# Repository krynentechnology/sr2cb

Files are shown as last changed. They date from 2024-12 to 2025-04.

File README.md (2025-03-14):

# SR2CB
<p>The Synchronous Redundant Ring Channel Bus (<i>S-R-square-C-Bus</i>) is a data bus with a open ring topology where a data <i>channel</i> is constructed from successive frames fixed bit/bits/byte/word/dword/qword/etc. positions. The
SR2CB network protocol supports <i>synchronous</i> operation by means of a distributed clock mechanism. Each ring node has two full duplex (TX/RX) hardware ports.</p>

<p>The physical interface (<i>layer</i>) between SR2CB nodes is based on 1000BASE-T, 100BASE-TX, RS-485 or LVDS. 1000BASE-T and 100BASE-TX PHYs are also common for the ethernet network physical layer but not bound to transmit solely ethernet frames. The SR2CB frames are continuously transmitted by the ring nodes clockwise and counterclockwise. Slave nodes retransmit those SR2CB frames after receipt and insert or extract channel data 'on the fly'. Within a SR2CB master/slave ring the single master node starts the redundant ring initialization and transmits the SR2CB frames. Master nodes do not pass SR2CB frames around except for a broken redundant ring (<i>single point of failure</i>) or when the redundant ring is exclusivly build from master nodes.</p>

<p>SR2CB (master) protocol HW setup for <a href="c10lp/README.md">Intel&reg; Cyclone&reg; 10 LP Evaluation Kit</a> and <a href="ecp5/README.md">Lattice Semiconductor&reg; ECP5&#8482; Development Board</a>.</p>

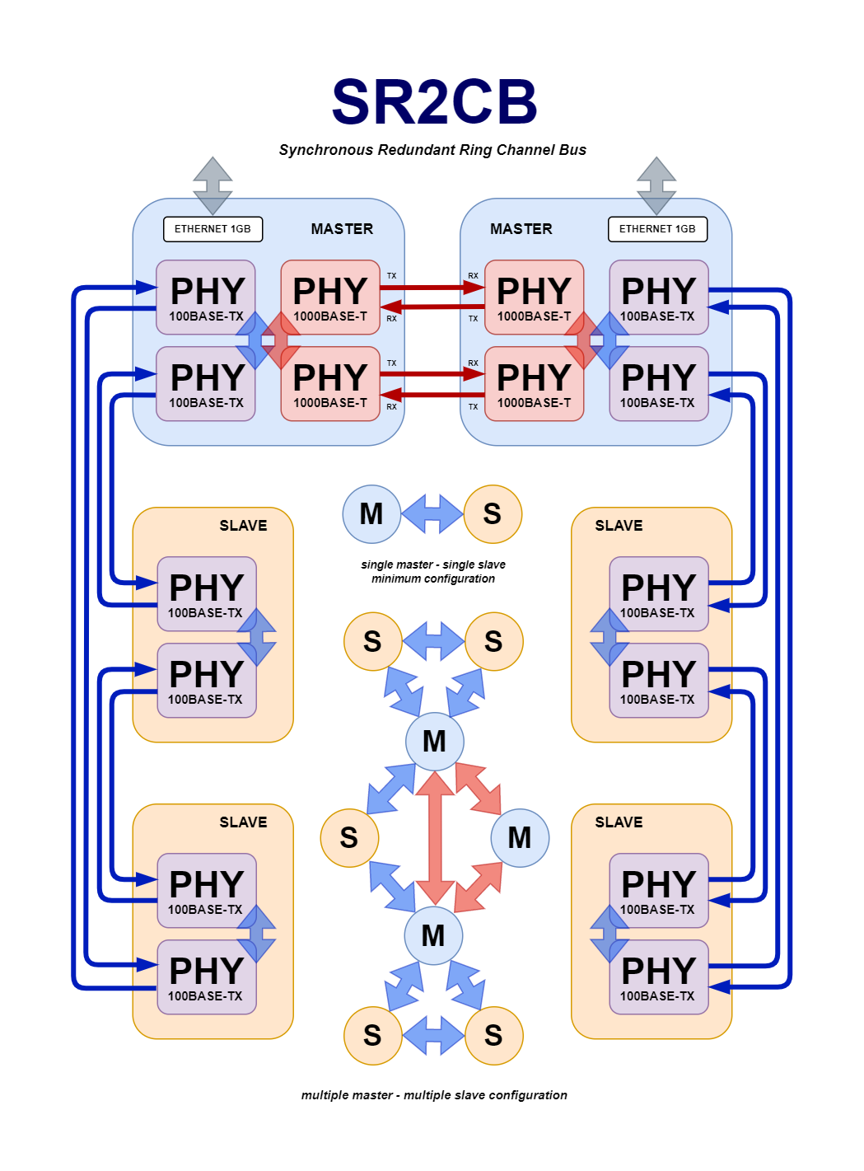
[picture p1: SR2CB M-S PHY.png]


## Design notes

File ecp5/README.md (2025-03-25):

# ECP5
<p>SR2CB protocol HW setup for Lattice Semiconductor&reg; ECP5&#8482; Development Board with cross-wired RJ-45 cable.</p>

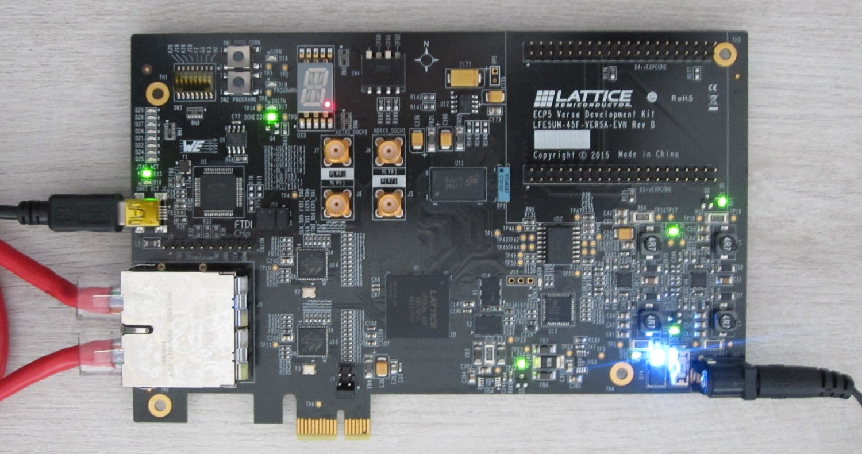
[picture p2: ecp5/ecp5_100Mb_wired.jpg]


<p>The Lattice Semiconductor&reg; ECP5&#8482; Development Board has two 1Gb/s Ethernet PHYs (Marvell 88E1512) and those should be setup for 100Mb/s with a cross-wired RJ-45 cable via a terminal connection. The SR2CB FPGA logic provides an UART/TTL terminal connection via the ECP5&#8482; Development Board FDTI USB port. The ECP5&#8482; Versa Development Board has from factory its FDTI FT2232H EEPROM not correctly configured for UART use. Reconfigure EEPROM by FT_PROG utility from FDTI - "Scan and parse". Set "Hardware Specific" - port B to UART and VCP (Virtual COM Port) and reprogram FT2232H EEPROM.</p>

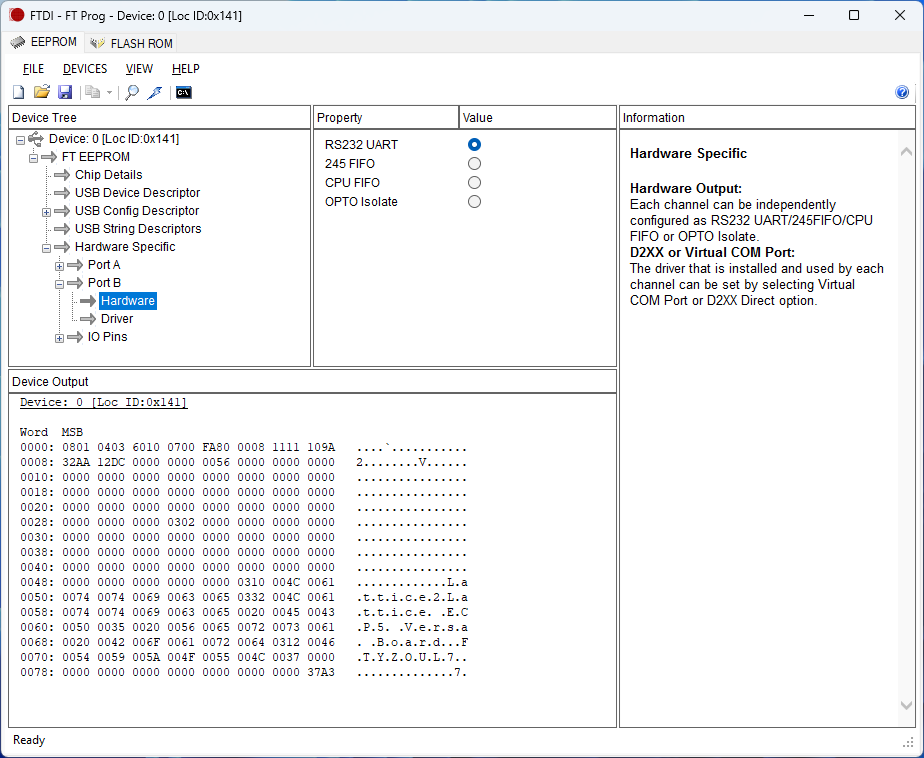
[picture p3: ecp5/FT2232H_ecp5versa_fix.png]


<p>The terminal commands "00A100" and "20A100" (write 0xA100 to PHY1 and PHY2 register 0 - Copper Control) forces the PHYs to 100Mb full duplex. Force link up for a continuous PHYs RXCLK with terminal commands "100400" and "300400" (write 0x0400 to PHY1 and PHY2 register 16 - 0x10/0x30). Read PHYs register 17 - 0x11/0x31 (Copper Specific Status Register 1 - 100Mbps, full duplex, auto-negotiation resolved and (copper) link-up). The terminal command "803" sets the PHYs link up bits in the SR2CB FPGA logic and the SR2CB master starts sending SR2CB frames. The ring 0 and 1 status is shown by "80" and "81" (4 = eR_READY).</p>

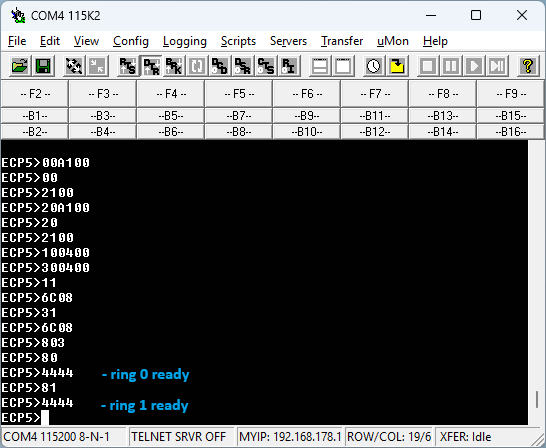
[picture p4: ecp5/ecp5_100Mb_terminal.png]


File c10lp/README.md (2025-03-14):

# C10LP
<p>SR2CB (master) protocol HW setup for Intel&reg; Cyclone&reg; 10 LP Evaluation Kit with 100Mb (fast ethernet) RJ-45 loopback plug - connect pin 1 (TX+) to 3 (RX+) and pin 2 (TX-) to 6 (RX-).</p>

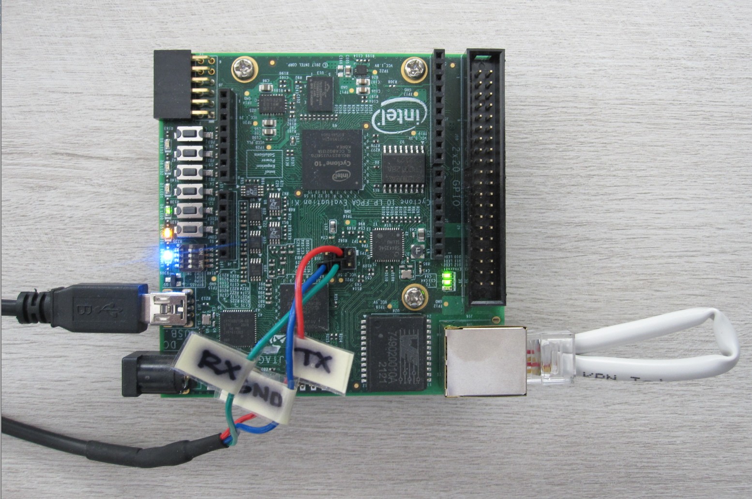
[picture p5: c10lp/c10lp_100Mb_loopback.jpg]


<p>The Intel&reg; Cyclone&reg; 10 LP Evaluation Kit has a 1Gb/s Ethernet PHY (MaxLinear GPY111-PEF7071) and should be setup for 100Mb/s with a two-wired RJ-45 loopback plug via a terminal connection. The SR2CB FPGA logic provides an UART/TTL terminal connection via three pins (RX/TX/GND) of the C10LP J18 haeder. The terminal command "002100" (write 0x2100 to PHY register 0x00 STD_CTRL) forces the PHY to 100Mb full duplex - 100Mb and linkup LEDs should light. Read PHY registers 0x17 (PCY_MIICTRL - RXCLK is active also when link is down, copper data flow, RGMII mode) and 0x18 (PHY_MIISTAT - full duplex, 100Mbit/s) to verify set configuration.</p>

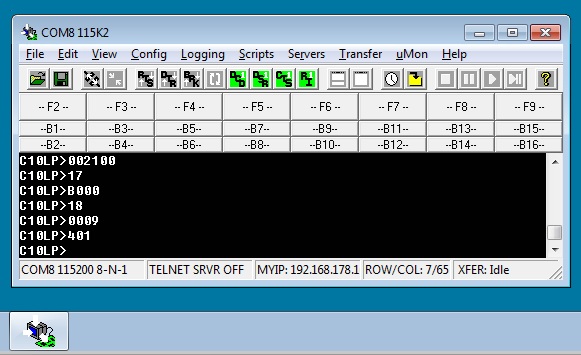
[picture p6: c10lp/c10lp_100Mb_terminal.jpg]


<p>The terminal command "401" sets the PHY link up bit in the SR2CB FPGA logic and the SR2CB master starts sending SR2CB frames.</p>

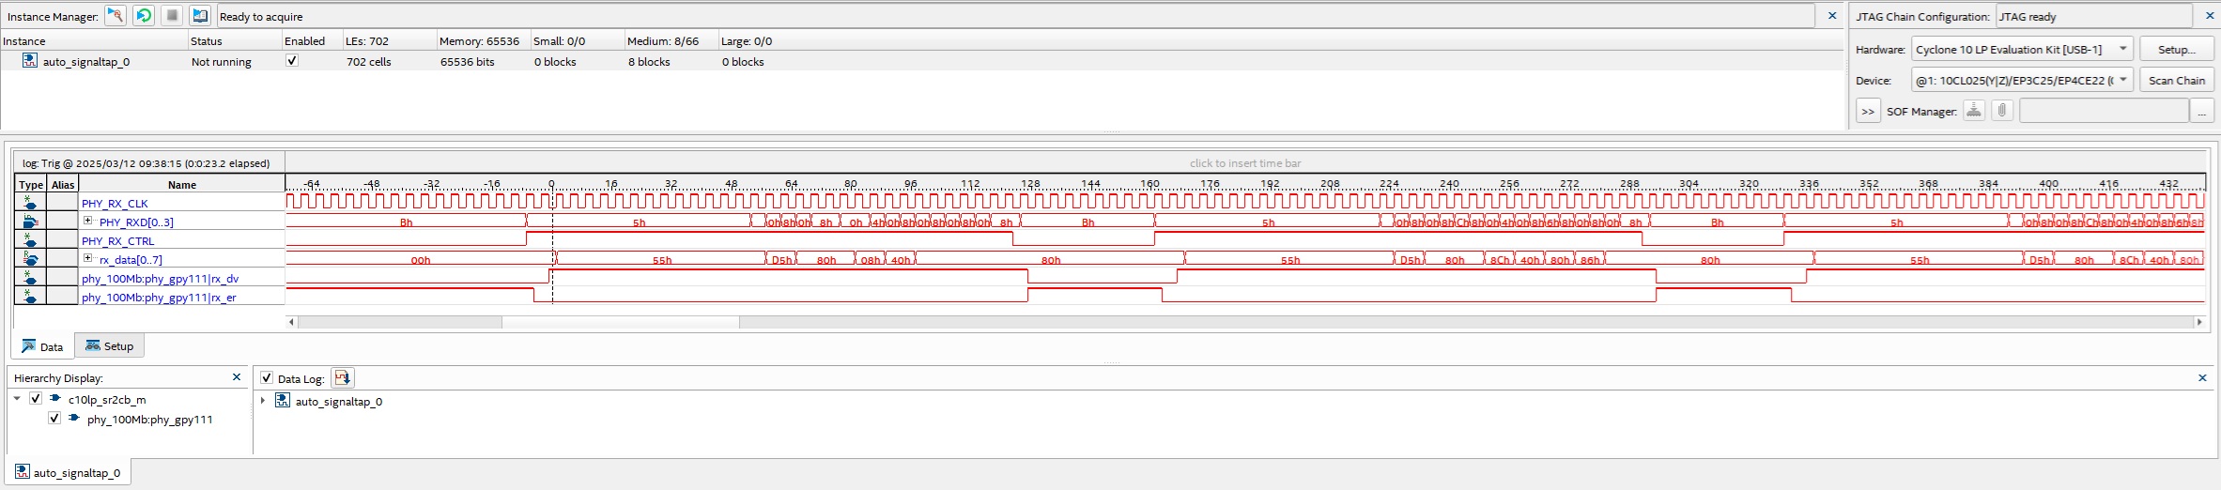
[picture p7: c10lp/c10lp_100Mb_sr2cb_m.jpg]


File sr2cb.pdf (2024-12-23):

Copyright © 2024 Kees Krijnen

# SR2CB

Introduction
The Synchronous Redundant Ring Channel Bus (S-R-square-Channel-Bus) is a data bus with a open ring topology where a data channel is constructed from successive frames fixed bit/bits/byte/word/dword/qword/etc. positions. The SR2CB network protocol supports synchronous operation by means of a distributed clock mechanism. Each ring node has two full duplex (TX/RX) hardware ports.
The physical interface (layer) between SR2CB nodes is based on 1000BASE-T, 100BASE-TX, RS-485 or LVDS. 1000BASE-T and 100BASE-TX PHYs are also common for the ethernet network physical layer but not bound to transmit solely ethernet frames. The SR2CB frames are continuously transmitted by the ring nodes clockwise and counterclockwise. Slave nodes retransmit those SR2CB frames after receipt and insert or extract channel data 'on the fly'. Within a SR2CB master/slave ring the single master node starts the redundant ring initialization and transmits the SR2CB frames. Master nodes do not pass SR2CB frames around except for a broken redundant ring (single point of failure) or when the redundant ring is exclusively build from master nodes.

Contents
- Network
- Packets and frames
- Clock synchronization

Network
A minimum SR2CB system configuration consist of a single master and a single slave. The number of slave nodes could be extended to a maximum of 8192 slave nodes for each master/slave ring. Each node has a packet propagation delay of about 0.5 us, so a ring with the maximum number of nodes has a total delay of ~4 ms. This is the maximum packet delay between the slave nodes adjacent to the master (counter and counterclockwise first ring node position). Multiple SR2CB master devices could assemble a ring where data channels from different master/slave ring configurations could be shared.

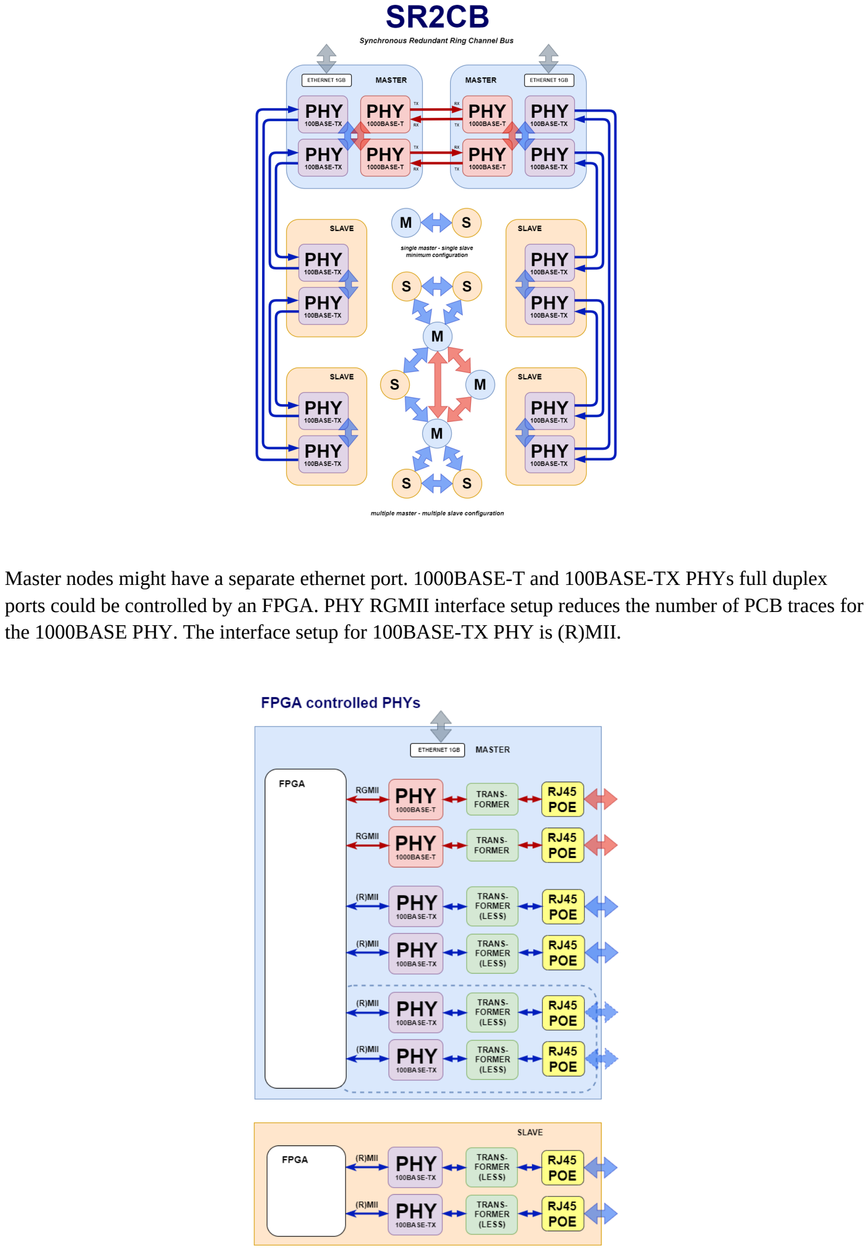
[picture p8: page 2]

Master nodes might have a separate ethernet port. 1000BASE-T and 100BASE-TX PHYs full duplex ports could be controlled by an FPGA. PHY RGMII interface setup reduces the number of PCB traces for the 1000BASE PHY. The interface setup for 100BASE-TX PHY is (R)MII.

Packets and frames
The number of SR2CB frames per second depends on the frame packet size which for the 'ethernet' PHYs starts with a SFD (Start Frame Delimeter) byte preceding by seven preamble bytes and ends with an IPG (Idle Packet Gap) sequence of five bytes. An audio application 20k SR2CB frames per second gives a byte channel speed of 160kb/s (20k times 8 bits) and offers 608 byte channels for 100BASE-TX and 6233 byte channels for 1000BASE-T PHYs. For the 1000BASE-T PHYs stable jumbo frames support is assumed, otherwise smaller frame sizes should be applied where some upper bits from the node position could indicate a frame ID. The 160kb/s is high enough for good audio quality APCM (32kHz voice - low latency - described in the Bluetooth A2DP specification) and Opus (48kHz voice and music) codecs - if required AES encrypted and authenticated.

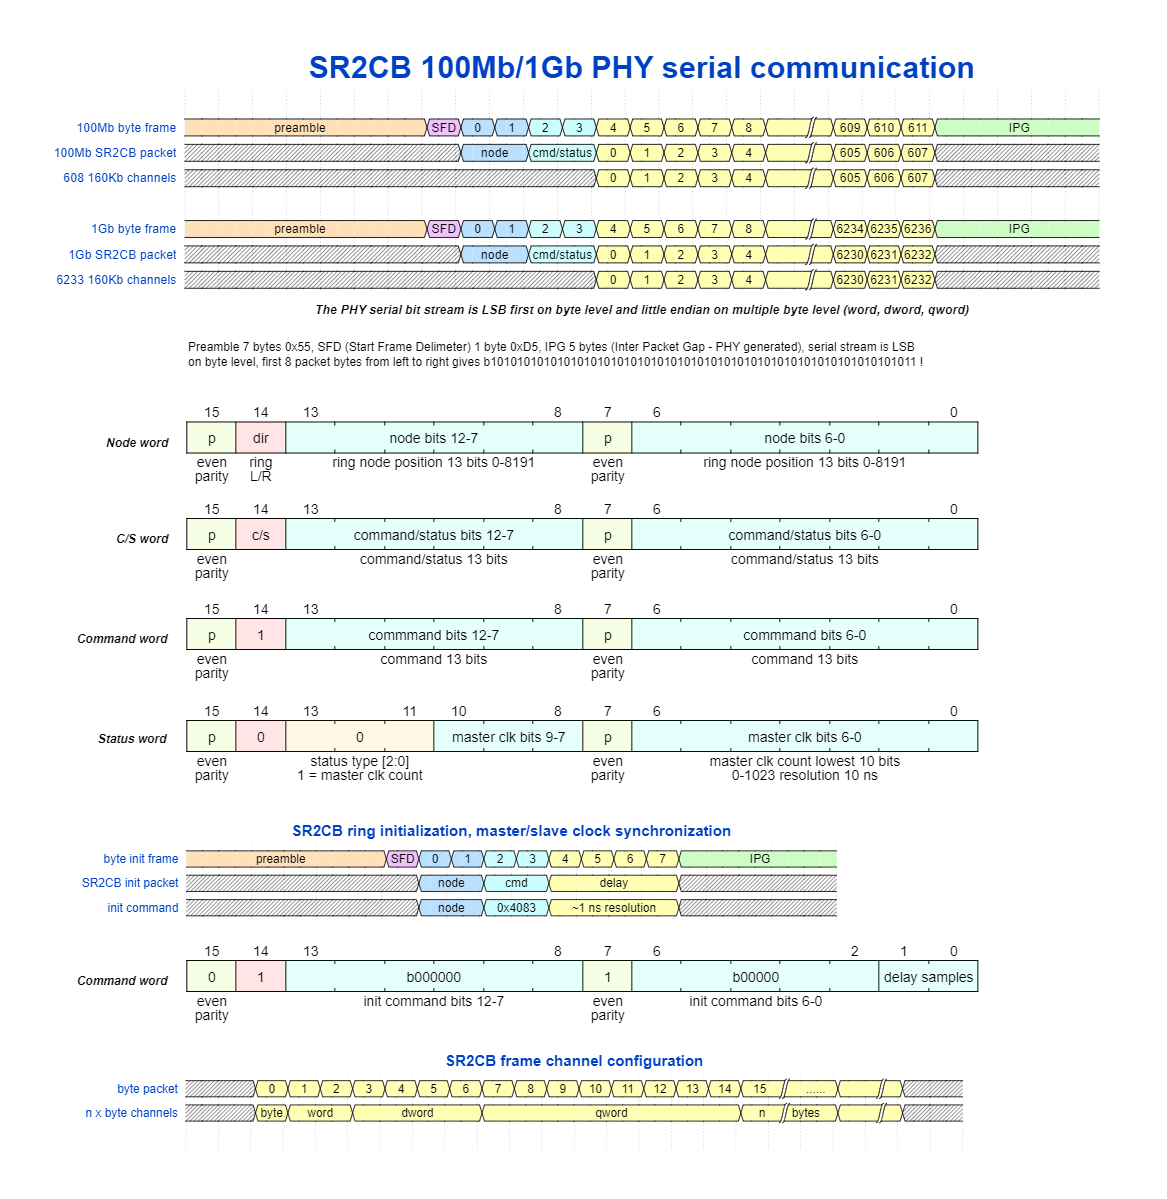
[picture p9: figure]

Clock synchronization
The master/slave nodes clock synchronization starts when all devices are powered up and (redundant) physical links have been established. The SR2CB master sends a clock synchronization command to one of the adjacent (ring clockwise or counterclockwise) connected slave nodes and counts the delay (10ns resolution) until this slave node returns this message (TX/RX data valid signal). This command could be sent repeated two, four or eight times; each time after the RX data valid signal is low again. The calculated delay is the delay count divided by 2 times the number of delay samples (1, 2, 4 or 8) and sent to the slave node with a clock sync delay set command. The delay sent is a 28-bit 24.4 fractional value where the upper 24-bit represent the determined 10ns resolution delay. The slave node also returns this delay set message and stops returning received (clock sync) command messages afterwards, but will start passing status messages received from slave nodes with higher node positions. All messages returned by slave nodes are status messages, the command bit in the C/S word has been reset.
The SR2CB master continues sending a clock sync delay set command to the adjacent node (ring clockwise or counterclockwise) until all slave nodes have replied with a delay set status message. The master determines the last slave node by checking the slave node positions in the returned messages. The master receives messages from both RX ports (passed command and returned status messages). When the returned slave node position does not increment anymore, this node position indicates the last slave node position in the open ring. The received command messages from the other RX port directly indicate the number of slave nodes. When a slave node could not establish a physical link with its own adjacent node, it flips the direction bit (ring L/R) in the returned node word, indicating a broken ring. This is also clear when the master receives no command messages from the other RX port (or this TX/RX port could not establish a physical link).
Each of the slave nodes determine the delay to the adjacent node by passing the master clock synchronization command messages, count the delay until the adjacent node returns the message and calculate the delay as the SR2CB master does. The clock sync delay set command is sent to the adjacent node when its own delay (delay time from master) has been set and the delay to the adjacent node has been calculated. Each slave node adds the calculated delay to the delay set before it sends the clock sync delay set command to the adjacent node.
When the SR2CB master has collected the delays set from all slave nodes from one ring direction (clockwise or counterclockwise) it starts collecting the slave node delays set from the other ring direction. Each slave node provides two different delays set (except when there is a single slave node), depending on which master ring port the clock sync commands are received from. The SR2CB master sends a clock reset command to both rings when the delays set have been collected from both rings and resets its own 10ns resolution clock counter. Each slave node has two internal 68-bit (64.4 fractional - the 64 bit represents 10ns resolution) clock counters, one for each RX port. Those counters are reset on receipt of the clock reset command message.
The master/slave node clock crystals have an accuracy of generally 50ppm or better. Multiple 100Mhz clock crystals could deviate a maximum clock count of 5000 in one second (50ppm - 50*100). This means that the SR2CB master clock status message which represent the lowest 10 bits of the master clock counter, should be sent at least once in 100ms (in both ring directions). In practice the SR2CB master clock count status message will be sent when no other C/S messages are sent. The slave nodes two counter values (ring L/R) added with the delays set should match the master clock counter value. On receipt of the master clock status message slave nodes calculate the difference with their two clock values and start adding 9-15 when their clock count value is higher than the master clock, or adding 17-23 when their clock count value is lower than the master clock. This adding of a 5-bit 1.4 fractional value (9-23) stabilizes to an optimal value (around 16) for each 10ns increment of the internal 10ns resolution 64.4 bit clock counters. A filter is applied to prevent oscillation.
In the above SR2CB protocol the command/status field is represented by one word (2 bytes). When the command/status field is represented by five words (10 bytes), it would allow the master to send the full 64-bit master clock value. It would decrease the available number of byte channels by eight.

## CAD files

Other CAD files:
c10lp/c10lp_sr2cb_m.stp

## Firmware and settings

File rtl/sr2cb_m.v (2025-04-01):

/**
 *  Copyright (C) 2024, 2025, Kees Krijnen.
 *
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
 *  License: LGPL, v3, as defined and found on www.gnu.org,
 *           https://www.gnu.org/licenses/lgpl-3.0.html
 *
 *  Description: SR2CB master node implementation.
 */

`resetall
`timescale 1ns / 1ps
`default_nettype none

// Dependencies:
`include "sr2cb_def.v"

/*============================================================================*/
module sr2cb_m #(
/*============================================================================*/
    parameter NR_CHANNELS = 608,
    parameter [0:0] PREAMBLE_SFD = 1 )
    (
    clk, rst_n,
    rx0tx0_link, rx0_loopback,
    rx0_clk, rx0_d, rx0_dv, rx0_err, // _d = data, _dv = data valid
    tx0_clk, tx0_d, tx0_dv, tx0_dr, tx0_err, // _dr = data ready
    rx1tx1_link, rx1_loopback,
    rx1_clk, rx1_d, rx1_dv, rx1_err,
    tx1_clk, tx1_d, tx1_dv, tx1_dr, tx1_err,
    rx0_ch_d, rx0_ch_dv, rx0_ch_dr, tx0_ch_d, rx0_tx0_ch, // _ch = channel
    rx1_ch_d, rx1_ch_dv, rx1_ch_dr, tx1_ch_d, rx1_tx1_ch,
    rx0_node_pos, rx0_c_s, // _c_s = command/status
    rx1_node_pos, rx1_c_s,
    rx0_status, rx0_delay,
    rx1_status, rx1_delay,
    tx0_status, tx0_c_s,
    tx1_status, tx1_c_s,
    tx0rx0_valid,
    tx1rx1_valid,
    ring_reset_pending,
    clk_count,
    dv_en // Debug signals
    );

localparam MAX_CLOG2_WIDTH = 16;
/*============================================================================*/
function integer clog2( input [MAX_CLOG2_WIDTH-1:0] value );
/*============================================================================*/
    reg [MAX_CLOG2_WIDTH-1:0] depth;
    begin
        clog2 = 1; // Minimum bit width
        if ( value > 1 ) begin
            depth = value - 1;
            clog2 = 0;
            while ( depth > 0 ) begin
                depth = depth >> 1;
                clog2 = clog2 + 1;
            end
        end
    end
endfunction

localparam NODE_POS_OFFSET = PREAMBLE_SFD * 8;
localparam CHANNEL_OFFSET  = NODE_POS_OFFSET + 4;
localparam CHW = clog2( NR_CHANNELS ); // Channel width
localparam NRBW = clog2( NR_CHANNELS + CHANNEL_OFFSET ); // RX bytes counter width
localparam TX_WAIT_STATES = 4;

input  wire clk;
input  wire rst_n; // Synchronous reset, high when clk is stable!
input  wire rx0tx0_link; // RX0/TX0 link up indication
output wire rx0_loopback; // RX0->TX0 loopback
input  wire rx0_clk;
input  wire [7:0] rx0_d; // Byte read node data
input  wire rx0_dv; // Read node data valid R0
input  wire rx0_err; // RX error
output wire tx0_clk;
output wire [7:0] tx0_d; // Byte write node data
output wire tx0_dv; // Write node data valid R0
input  wire tx0_dr; // Ready for node data
output reg  tx0_err = 0; // TX error
input  wire rx1tx1_link; // RX1/TX1 link up indication
output wire rx1_loopback; // RX1->TX1 loopback
input  wire rx1_clk;
input  wire [7:0] rx1_d; // Byte read node data
input  wire rx1_dv; // Read node data valid R1
input  wire rx1_err; // RX error
output wire tx1_clk;
output wire [7:0] tx1_d; // Byte node write data
output wire tx1_dv; // Write node data valid R1
input  wire tx1_dr; // Ready for node data
output reg  tx1_err = 0; // TX error
input  wire [7:0] rx0_ch_d; // Byte read channel data
input  wire rx0_ch_dv; // Read channel data valid R0
output wire rx0_ch_dr; // Read channel data ready R0
output reg  [7:0] tx0_ch_d = 0; // Byte write channel data
output wire [CHW-1:0] rx0_tx0_ch; // Channel address (0 - NR_CHANNELS-1)
input  wire [7:0] rx1_ch_d; // Byte read channel data
input  wire rx1_ch_dv; // Read channel data valid R1
output wire rx1_ch_dr; // Read channel data ready R1
output reg  [7:0] tx1_ch_d = 0; // Byte write channel data
output wire [CHW-1:0] rx1_tx1_ch; // Channel address (0 - NR_CHANNELS-1)
output reg  [12:0] rx0_node_pos = 0;
output reg  [13:0] rx0_c_s = 0; // Command/status ( + command/status bit)
output reg  [2:0] rx0_status = 0;
output reg  [27:0] rx0_delay = 0;
output reg  [12:0] rx1_node_pos = 0;
output reg  [13:0] rx1_c_s = 0; // Command/status ( + command/status bit)
output reg  [2:0] rx1_status = 0;
output reg  [27:0] rx1_delay = 0;
output reg  [2:0] tx0_status = 0;
input  wire [12:0] tx0_c_s; // Command/status
output reg  [2:0] tx1_status = 0;
input  wire [12:0] tx1_c_s; // Command/status
output reg  tx0rx0_valid = 0; // rx0_node_pos, rx0_c_s, rx0_delay valid
output reg  tx1rx1_valid = 0; // rx1_node_pos, rx1_c_s, rx1_delay valid
output wire ring_reset_pending;
output wire [63:0] clk_count; // Actual master clock count
output wire [1:0] dv_en; // Debug signals
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

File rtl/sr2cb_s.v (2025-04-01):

/**
 *  Copyright (C) 2024, 2025, Kees Krijnen.
 *
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
 *  License: LGPL, v3, as defined and found on www.gnu.org,
 *           https://www.gnu.org/licenses/lgpl-3.0.html
 *
 *  Description: SR2CB slave node implementation.
 */

`resetall
`timescale 1ns / 1ps
`default_nettype none

// Dependencies:
// `include "../lib/randomizer.v"
`include "sr2cb_def.v"

/*============================================================================*/
module sr2cb_s #(
/*============================================================================*/
    parameter NR_CHANNELS = 608,
    parameter [0:0] PREAMBLE_SFD = 1 )
    (
    clk, rst_n,
    rx0_clk, rx0_d, rx0_dv, rx0_err, // _d = data, _dv = data valid
    tx0_clk, tx0_d, tx0_dv, tx0_dr, tx0_err, // _dr = data ready
    rx1_clk, rx1_d, rx1_dv, rx1_err,
    tx1_clk, tx1_d, tx1_dv, tx1_dr, tx1_err,
    rx0_ch_d, rx0_ch_dv, rx0_ch_dr, tx0_ch_d, rx0_tx0_ch, // _ch = channel
    rx1_ch_d, rx1_ch_dv, rx1_ch_dr, tx1_ch_d, rx1_tx1_ch,
    rx0_node_pos, rx0_c_s, // _c_s = command/status
    rx1_node_pos, rx1_c_s,
    rx0_status, rx0_delay, rx0_rt_clk_count, rx0_clk_adjust_fast,
    rx1_status, rx1_delay, rx1_rt_clk_count, rx1_clk_adjust_fast,
    clk_en, dv_en // Debug signals
    );

localparam MAX_CLOG2_WIDTH = 16;
/*============================================================================*/
function integer clog2( input [MAX_CLOG2_WIDTH-1:0] value );
/*============================================================================*/
    reg [MAX_CLOG2_WIDTH-1:0] depth;
    begin
        clog2 = 1; // Minimum bit width
        if ( value > 1 ) begin
            depth = value - 1;
            clog2 = 0;
            while ( depth > 0 ) begin
                depth = depth >> 1;
                clog2 = clog2 + 1;
            end
        end
    end
endfunction

localparam NODE_POS_OFFSET = PREAMBLE_SFD * 8;
localparam CHANNEL_OFFSET  = NODE_POS_OFFSET + 4;
localparam CLK_SYNC_OFFSET = ( NODE_POS_OFFSET + 1 ) * 8 * 16; // *16 [3:0]
localparam CHW = clog2( NR_CHANNELS ); // Channel width
localparam NRBW = clog2( NR_CHANNELS + CHANNEL_OFFSET ); // RX bytes counter width

input  wire clk;
input  wire rst_n; // Synchronous reset, high when clk is stable!
input  wire rx0_clk;
input  wire [7:0] rx0_d; // Byte read node data
input  wire rx0_dv; // Read node data valid R0
input  wire rx0_err; // RX error
output wire tx0_clk;
output wire [7:0] tx0_d; // Byte write node data
output wire tx0_dv; // Write node data valid R0
input  wire tx0_dr; // Ready for node data
output wire tx0_err; // TX error
input  wire rx1_clk;
input  wire [7:0] rx1_d; // Byte read node data
input  wire rx1_dv; // Read node data valid R1
input  wire rx1_err; // RX error
output wire tx1_clk;
output wire [7:0] tx1_d; // Byte node write data
output wire tx1_dv; // Write node data valid R1
input  wire tx1_dr; // Ready for node data
output wire tx1_err; // TX error
input  wire [7:0] rx0_ch_d; // Byte read channel data
input  wire rx0_ch_dv; // Read channel data valid R0
output wire rx0_ch_dr; // Read channel data ready R0
output reg  [7:0] tx0_ch_d = 0; // Byte write channel data
output wire [CHW-1:0] rx0_tx0_ch; // Channel address (0 - NR_CHANNELS-1)
input  wire [7:0] rx1_ch_d; // Byte read channel data
input  wire rx1_ch_dv; // Read channel data valid R1
output wire rx1_ch_dr; // Read channel data ready R1
output reg  [7:0] tx1_ch_d = 0; // Byte write channel data
output wire [CHW-1:0] rx1_tx1_ch; // Channel address (0 - NR_CHANNELS-1)
output reg  [12:0] rx0_node_pos = 0;
output reg  [13:0] rx0_c_s = 0; // Command/status
output reg  [2:0] rx0_status = 0;
output reg  [27:0] rx0_delay = 0;
output wire [67:0] rx0_rt_clk_count; // Real-time R0 clock count
output reg  rx0_clk_adjust_fast = 0; // Monitor for external clk changes
output reg  [12:0] rx1_node_pos = 0;
output reg  [13:0] rx1_c_s = 0; // Command/status
output reg  [2:0] rx1_status = 0;
output reg  [27:0] rx1_delay = 0;
output wire [67:0] rx1_rt_clk_count; // Real-time R1 clock count
output reg  rx1_clk_adjust_fast = 0; // Monitor for external clk changes
output wire [3:0] clk_en;
output wire [3:0] dv_en;

// Registers and wires
reg         clk00_en = 0;
reg         clk01_en = 0;
reg   [7:0] rx00_d_i = 0;
reg   [7:0] rx01_d_i = 0;
reg         dv00_en = 0;
reg         dv01_en = 0;
reg         rx0_dv_i = 0;
wire  [7:0] rx0_node_pos_c;
reg         rx0_node_pos_carry = 0;
wire        rx0_node_pos_inc;
reg         rx0_parity_ok = 0;
wire        rx0_parity_ok_c;
reg  [NRBW-1:0] rx0_nb_bytes = 0;
wire [27:0] rx0_delay_c;
wire        rx0_idle;
wire        rx0_pre_init;
wire        rx0_init;
wire        rx0_wait;
wire        rx0_ready;
reg   [2:0] rx0_status_i = `eR_IDLE;
reg         rx0_error = 0;
wire        rx0_cmd_nop;
wire        rx0_clk_sync_c_s;
wire        rx0_clk_sync_cmd;
wire        rx0_clk_sync_set_cmd;
wire        rx0_clk_reset_cmd;
wire        rx0_mclk_status;
reg         rx0_delay_set = 0;
/*---------------------------*/
reg         clk11_en = 0;
reg         clk10_en = 0;
reg   [7:0] rx11_d_i = 0;
reg   [7:0] rx10_d_i = 0;
reg         dv11_en = 0;
reg         dv10_en = 0;
reg         rx1_dv_i = 0;
wire  [7:0] rx1_node_pos_c;
reg         rx1_node_pos_carry = 0;
wire        rx1_node_pos_inc;
reg         rx1_parity_ok = 0;
wire        rx1_parity_ok_c;
reg  [NRBW-1:0] rx1_nb_bytes = 0;
wire [27:0] rx1_delay_c;
wire        rx1_idle;
wire        rx1_pre_init;
wire        rx1_init;
wire        rx1_wait;
wire        rx1_ready;
reg   [2:0] rx1_status_i = `eR_IDLE;
reg         rx1_error = 0;
wire        rx1_cmd_nop;
wire        rx1_clk_sync_c_s;
wire        rx1_clk_sync_cmd;
wire        rx1_clk_sync_set_cmd;
wire        rx1_clk_reset_cmd;
wire        rx1_mclk_status;
reg         rx1_delay_set = 0;
/*---------------------------*/
reg [10:0] delay_count = 0;
reg [14:0] delay_rx01_count = 0;
reg [14:0] delay_rx10_count = 0;
/*---------------------------*/
reg  rx0_reset = 0;
reg  rx1_reset = 0;
wire rx0_ring_reset_cmd;
wire rx1_ring_reset_cmd;
wire ring_reset_cmd;
/*---------------------------*/

localparam LFSR_TAP_WIDTH = 8;
wire [LFSR_TAP_WIDTH-1:0] random_out;
/*============================================================================*/
randomizer #(
/*============================================================================*/
    .NR_CHANNELS( 1 ),
    .OUTPUT_WIDTH( LFSR_TAP_WIDTH ))
random (
    .clk(clk),
    .rndm_ch(1'b0),
    .rndm_seed(8'h0),
    .rndm_init(~rst_n),
    .rndm_out(random_out),
    .rndm_ready(1'b1)
);
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

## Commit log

2024-05-26 Add files via upload
    Update SR2CB packet and frame picture
2024-11-13 Add redundant ring reset
    [sr2cb_m.v, sr2cb_s.v, sr2cb_tb.sv]
2025-02-07 Add UART
2025-02-19 Add UART IO (console)
2025-03-12 Add 100Mb/s PHY logic and C10LP HW setup
    [c10lp_sr2cb_m.stp]

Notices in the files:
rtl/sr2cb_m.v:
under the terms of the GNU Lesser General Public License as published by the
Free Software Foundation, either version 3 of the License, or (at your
